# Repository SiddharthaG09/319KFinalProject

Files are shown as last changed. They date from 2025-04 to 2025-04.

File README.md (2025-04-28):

# 319KFinalProject

For our final project, we recreated Space Invaders in C, using a custom-designed PCB and an MSPM0G3507 microcontroller. The game integrates hardware components including buttons, a slide potentiometer, and a DAC to control gameplay elements. We designed, printed, and assembled the PCB ourselves, and developed the game logic and graphics from scratch to run on the microcontroller.

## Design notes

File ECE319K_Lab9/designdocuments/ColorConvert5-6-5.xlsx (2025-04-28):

red | green | blue | 565
0 | 255 | 120 | 0x7FE0 | 0x7FE0, // 0, 255, 120

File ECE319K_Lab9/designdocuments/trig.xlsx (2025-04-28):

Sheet: 64
 | 2 |  | 64
angle | vx | vy | ix | iy
0 | 2 | 0 | 128 | 0
0.09817477042 | 1.990369453 | 0.1960342807 | 127 | 13
0.1963495408 | 1.961570561 | 0.390180644 | 126 | 25
0.2945243113 | 1.913880671 | 0.5805693545 | 122 | 37
0.3926990817 | 1.847759065 | 0.7653668647 | 118 | 49
0.4908738521 | 1.763842529 | 0.9427934737 | 113 | 60
0.5890486225 | 1.662939225 | 1.111140466 | 106 | 71
0.687223393 | 1.546020907 | 1.268786568 | 99 | 81
0.7853981634 | 1.414213562 | 1.414213562 | 91 | 91
0.8835729338 | 1.268786568 | 1.546020907 | 81 | 99
0.9817477042 | 1.111140466 | 1.662939225 | 71 | 106
1.079922475 | 0.9427934737 | 1.763842529 | 60 | 113
1.178097245 | 0.7653668647 | 1.847759065 | 49 | 118
1.276272016 | 0.5805693545 | 1.913880671 | 37 | 122
1.374446786 | 0.390180644 | 1.961570561 | 25 | 126
1.472621556 | 0.1960342807 | 1.990369453 | 13 | 127
1.570796327 | -7.656635742e-16 | 2 | 0 | 128
1.668971097 | -0.1960342807 | 1.990369453 | -13 | 127
1.767145868 | -0.390180644 | 1.961570561 | -25 | 126
1.865320638 | -0.5805693545 | 1.913880671 | -37 | 122
1.963495408 | -0.7653668647 | 1.847759065 | -49 | 118
2.061670179 | -0.9427934737 | 1.763842529 | -60 | 113
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

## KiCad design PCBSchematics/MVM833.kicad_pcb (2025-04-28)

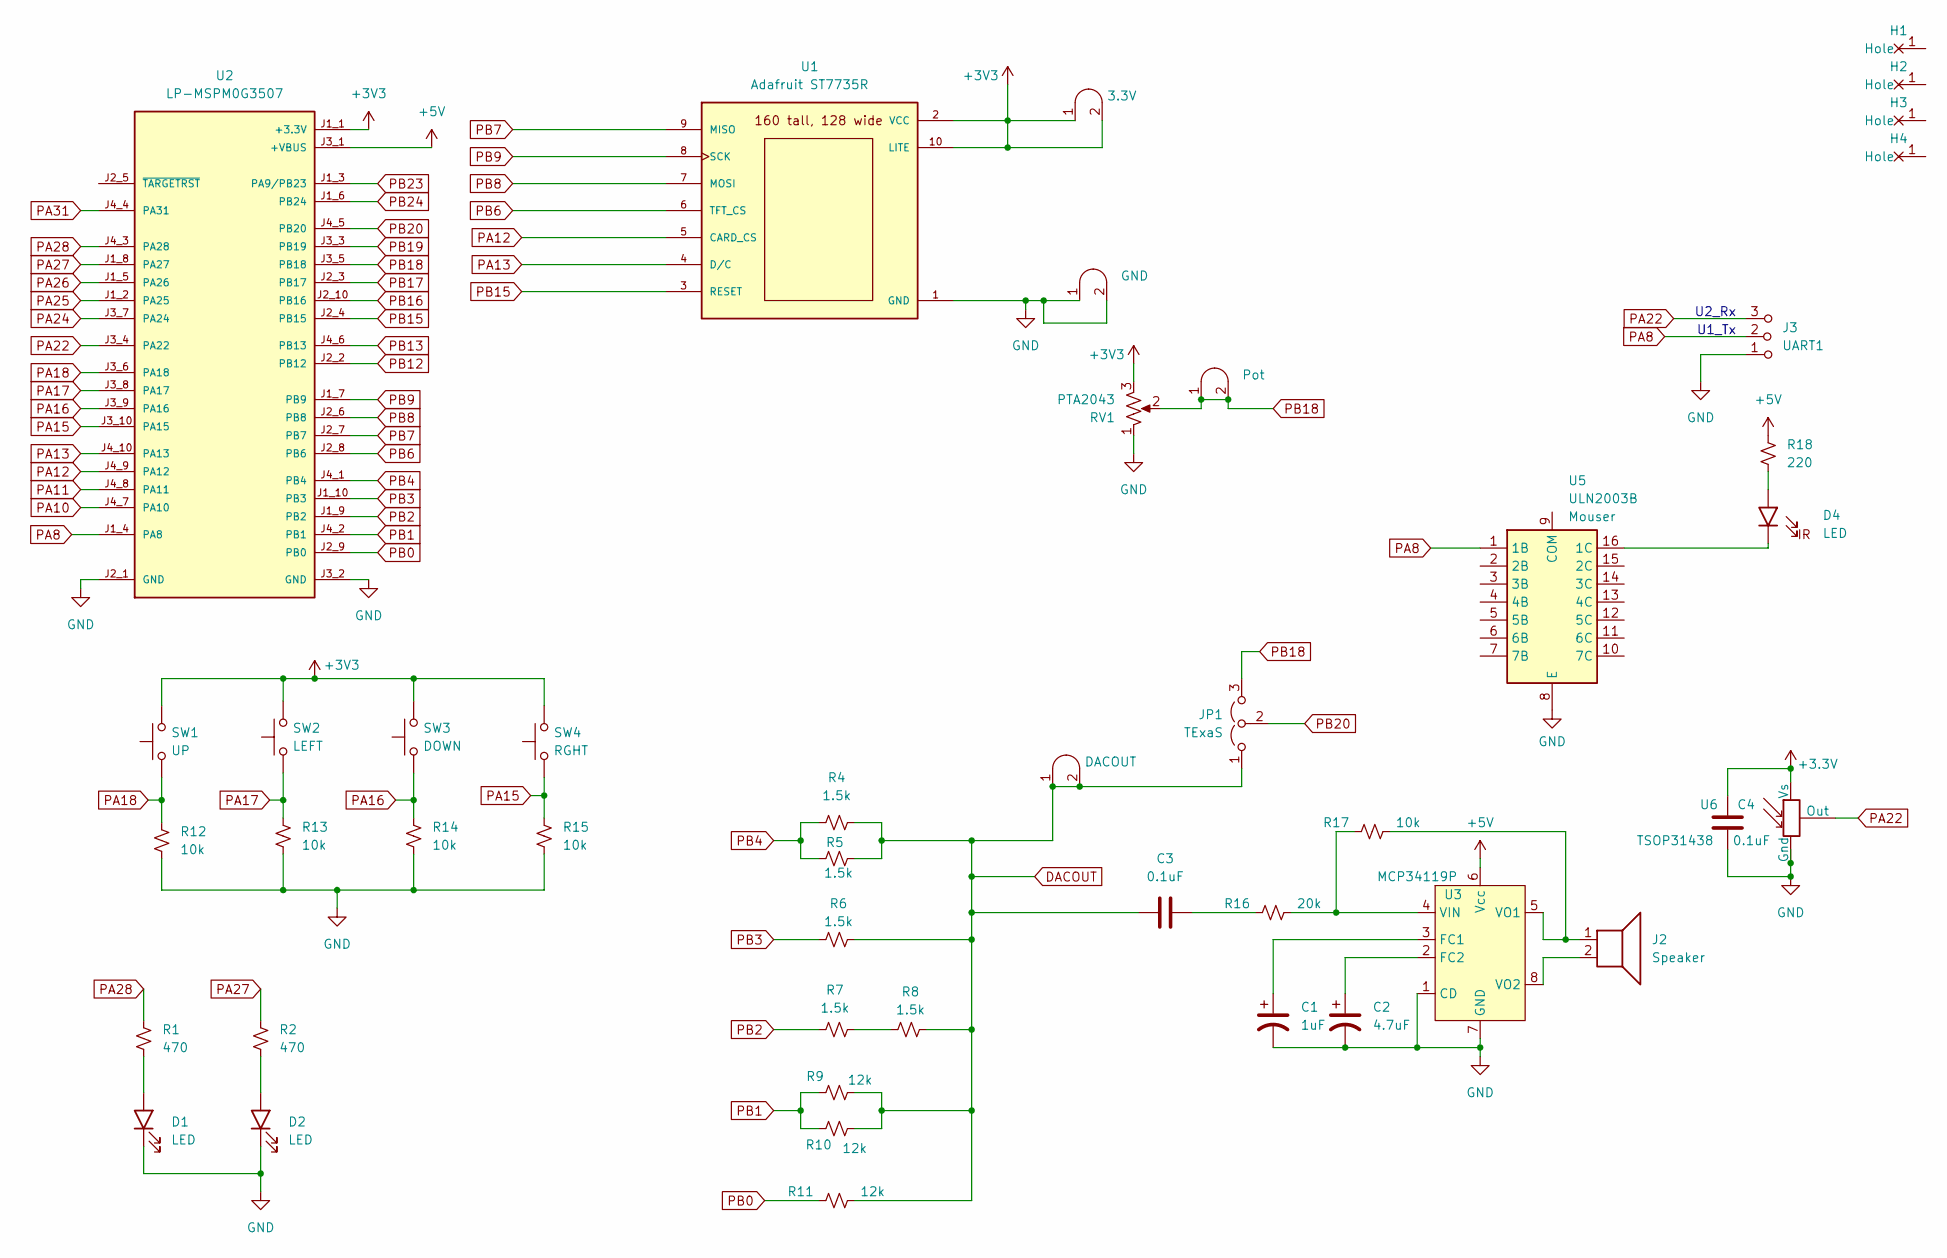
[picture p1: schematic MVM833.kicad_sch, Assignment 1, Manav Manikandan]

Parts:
C1: 1uF; CP_Radial_Tantal200mil
C2: 4.7uF; CP_Radial_Tantal200mil
C3, C4: 0.1uF; C_Axial_200mil
D1, D2, D4: LED; LED_D5.0mm
H1, H2, H3, H4: MountingHole_4_40
J2: Speaker; PinHeader_1x02_P2.54mm_Vertical
J3: UART1; PinHeader_1x03_P2.54mm_Vertical
J4: Pot; Testpoint_1x02_P2.54mm
J6: GND; Testpoint_1x02_P2.54mm
J7: DACOUT; Testpoint_1x02_P2.54mm
JP1: TExaS; PinHeader_1x03_P2.54mm_Vertical
R1, R2: 470; R_Axial_DIN0204_L3.6mm_D1.6mm_P7.62mm_Horizontal
R4, R5, R6, R7, R8: 1.5k; R_Axial_DIN0204_L3.6mm_D1.6mm_P7.62mm_Horizontal
R9, R10, R11: 12k; R_Axial_DIN0204_L3.6mm_D1.6mm_P7.62mm_Horizontal
R12, R13, R14, R15, R17: 10k; R_Axial_DIN0204_L3.6mm_D1.6mm_P7.62mm_Horizontal
R16: 20k; R_Axial_DIN0204_L3.6mm_D1.6mm_P7.62mm_Horizontal
R18: 220; R_Axial_DIN0204_L3.6mm_D1.6mm_P7.62mm_Horizontal
RV1: PTA2043; PTA2043pot
SW1: UP; SW_PUSH_6mm
SW2: LEFT; SW_PUSH_6mm
SW3: DOWN; SW_PUSH_6mm
SW4: RGHT; SW_PUSH_6mm
TP1: 3.3V; Testpoint_1x02_P2.54mm
U1: Adafruit ST7735R; adafruit_st7735r
U2: LP-MSPM0G3507; ti_LP_MSPM0G3507
U3: MCP34119P; DIP-8_W7.62mm_LongPads
U5: ULN2003B; DIP-16_W7.62mm
U6: TSOP31438

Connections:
+3.3V: C4.1, U6.2 (Vs)
+3V3: RV1.3, SW1.2, SW2.2, SW3.2, SW4.2, TP1.1 (A), TP1.2 (B), U1.2 (VCC), U1.10 (LITE), U2.J1_1 (+3.3V)
+5V: R18.1, U2.J3_1 (+VBUS), U3.6 (Vcc)
DACOUT: C3.1, J7.1 (A), J7.2 (B), JP1.1 (A), R4.1, R5.1, R6.1, R8.1, R9.1, R10.1, R11.1
GND: C1.2, C2.2, C4.2, D1.1 (K), D2.1 (K), J3.1 (A), J6.1 (A), J6.2 (B), R12.2, R13.2, R14.2, R15.2, RV1.1, U1.1 (GND), U2.J2_1 (GND), U2.J3_2 (GND), U3.1 (CD), U3.7 (GND), U5.8 (E), U6.1 (Gnd)
unnamed: C3.2, R16.2
unnamed: D1.2 (A), R1.2
unnamed: D2.2 (A), R2.2
unnamed: D4.2 (A), R18.2
unnamed: D4.1 (K), U5.16 (1C)
unnamed: R7.1, R8.2
unnamed: C1.1, U3.3 (FC1)
unnamed: C2.1, U3.2 (FC2)
unnamed: R16.1, R17.2, U3.4 (VIN)
unnamed: J2.1, R17.1, U3.5 (VO1)
unnamed: J2.2, U3.8 (VO2)
PA8: J3.2 (B), U2.J1_4 (PA8), U5.1 (1B)
PA10: U2.J4_7 (PA10)
PA11: U2.J4_8 (PA11)
PA12: U1.5 (CARD_CS), U2.J4_9 (PA12)
PA13: U1.4 (D/C), U2.J4_10 (PA13)
PA15: R15.1, SW4.1, U2.J3_10 (PA15)
PA16: R14.1, SW3.1, U2.J3_9 (PA16)
PA17: R13.1, SW2.1, U2.J3_8 (PA17)
PA18: R12.1, SW1.1, U2.J3_6 (PA18)
PA22: J3.3 (C), U2.J3_4 (PA22), U6.3 (Out)
PA24: U2.J3_7 (PA24)
PA25: U2.J1_2 (PA25)
PA26: U2.J1_5 (PA26)
PA27: R2.1, U2.J1_8 (PA27)
PA28: R1.1, U2.J4_3 (PA28)
PA31: U2.J4_4 (PA31)
PB0: R11.2, U2.J2_9 (PB0)
PB1: R9.2, R10.2, U2.J4_2 (PB1)
PB2: R7.2, U2.J1_9 (PB2)
PB3: R6.2, U2.J1_10 (PB3)
PB4: R4.2, R5.2, U2.J4_1 (PB4)
PB6: U1.6 (TFT_CS), U2.J2_8 (PB6)
PB7: U1.9 (MISO), U2.J2_7 (PB7)
PB8: U1.7 (MOSI), U2.J2_6 (PB8)
PB9: U1.8 (SCK), U2.J1_7 (PB9)
PB12: U2.J2_2 (PB12)
PB13: U2.J4_6 (PB13)
PB15: U1.3 (RESET), U2.J2_4 (PB15)
PB16: U2.J2_10 (PB16)
PB17: U2.J2_3 (PB17)
PB18: J4.1 (A), J4.2 (B), JP1.3 (B), RV1.2, U2.J3_5 (PB18)
PB19: U2.J3_3 (PB19)
PB20: JP1.2 (C), U2.J4_5 (PB20)
PB23: U2.J1_3 (PA9/PB23)
PB24: U2.J1_6 (PB24)

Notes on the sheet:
U2_Rx
U1_Tx

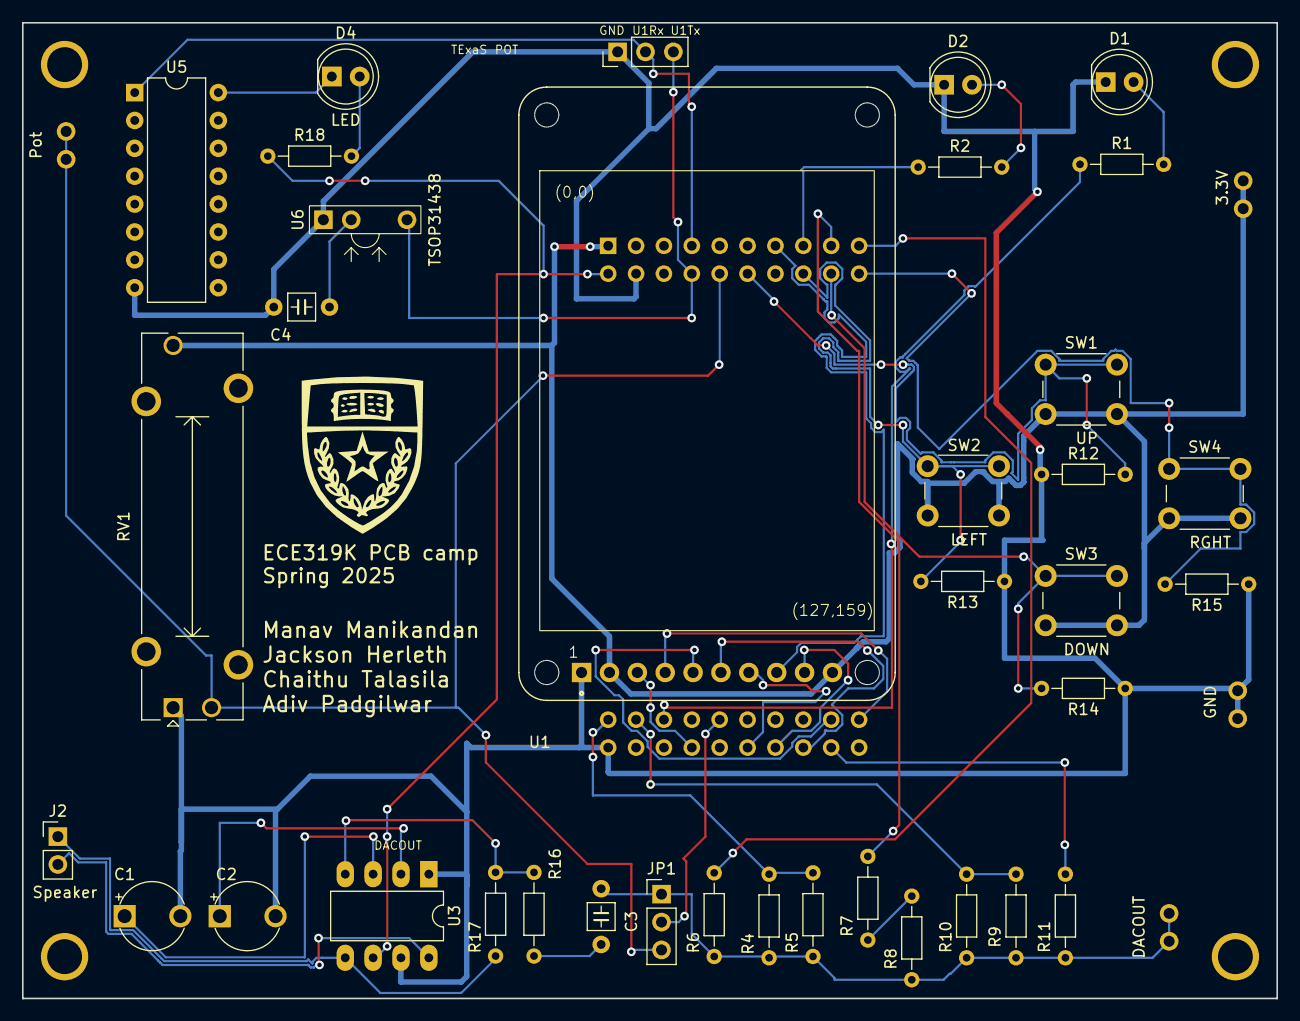
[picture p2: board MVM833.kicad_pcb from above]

Board: 2 copper layers, 114.3 x 88.9 mm, 45 parts (1 on the bottom side), 38 nets.

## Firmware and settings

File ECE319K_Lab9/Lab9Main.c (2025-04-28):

// Lab9Main.c
// Runs on MSPM0G3507
// Lab 9 ECE319K
// Your name
// Last Modified: 12/26/2024

#include <stdio.h>
#include <stdint.h>
#include <ti/devices/msp/msp.h>
#include "../inc/ST7735.h"
#include "../inc/Clock.h"
#include "../inc/LaunchPad.h"
#include "../inc/TExaS.h"
#include "../inc/Timer.h"
#include "../inc/ADC1.h"
#include "../inc/DAC5.h"
#include "../inc/Arabic.h"
#include "SmallFont.h"
#include "LED.h"
#include "Switch.h"
#include "Sound.h"
#include "images/images.h"
#include <stdlib.h>
#include <time.h>

int getRandomval(void) {
  return (rand() % (40 - 5 + 1)) + 5;
}

// PLL / clock setup
void PLL_Init(void){
  Clock_Init80MHz(0);
}

// Arabic demo data (unchanged)
Arabic_t ArabicAlphabet[] = {
  alif, ayh, baa, daad, daal, dhaa, dhaal,
  faa, ghayh, haa, ha, jeem, kaaf, khaa,
  laam, meem, noon, qaaf, raa, saad, seen,
  sheen, ta, thaa, twe, waaw, yaa, zaa,
  space, dot, null
};
Arabic_t Hello[] = { alif, baa, ha, raa, meem, null };
Arabic_t WeAreHonoredByYourPresence[] = { alif, noon, waaw, ta, faa, raa, sheen, null };

// simple 32-bit LCG for wider random range
static uint32_t M = 1;
uint32_t Random32(void){
  M = 1664525*M + 1013904223;
  return M;
}
uint32_t Random(uint32_t n){
  return (Random32() >> 16) % n;
}

// TExaS helper for PB27/PB26
uint8_t TExaS_LaunchPadLogicPB27PB26(void){
  return (0x80 | ((GPIOB->DOUT31_0 >> 26) & 0x03));
}

// language/phrase tables (unchanged)
typedef enum { English, Spanish, Portuguese, French } Language_t;
typedef enum { HELLO, GOODBYE, LANGUAGE } phrase_t;
const char Hello_English[]    = "Hello";
const char Hello_Spanish[]    = "\xADHola!";
const char Hello_Portuguese[] = "Ol\xA0";
const char Hello_French[]     = "All\x83";
const char Goodbye_English[]    = "Goodbye";
const char Goodbye_Spanish[]    = "Adi\xA2s";
const char Goodbye_Portuguese[] = "Tchau";
const char Goodbye_French[]     = "Au revoir";
const char Language_English[]    = "English";
const char Language_Spanish[]    = "Espa\xA4ol";
const char Language_Portuguese[] = "Portugu\x88s";
const char Language_French[]     = "Fran\x87" "ais";
const char *Phrases[3][4] = {
  { Hello_English, Hello_Spanish, Hello_Portuguese, Hello_French },
  { Goodbye_English, Goodbye_Spanish, Goodbye_Portuguese, Goodbye_French },
  { Language_English, Language_Spanish, Language_Portuguese, Language_French }
};

// game state
uint32_t laseractive = 0;
uint32_t score       = 0;
volatile uint32_t slideplot = 0;
uint32_t flag        = 1;
uint32_t end         = 0;
uint32_t respawn     = 0;

typedef struct {
  uint16_t *pic;
  int32_t posx, posy;
  int32_t w, l;
  int32_t health;
  int32_t vx, vy;
  int32_t prevx, prevy;
} ship_t;

ship_t bguys, me, laser;

// initialize enemy: full-width spawn, random speeds & drift
void bguys_init(void) {
  bguys.pic    = SmallEnemy30pointA;
  bguys.health = 1;
  bguys.w      = 16;
  bguys.l      = 10;

  // spawn X anywhere in [0, 128 - w]
  bguys.posx = Random(128 - bguys.w);
  bguys.posy = 5;

  // vertical speed ∈ {1,2,3}
  bguys.vy = Random(3) + 1;

  // horizontal speed ∈ { -2,-1,0,+1,+2 }
  {
    int dir = (int)Random(3) - 1;   // -1,0,+1
    int mag = (int)Random(2) + 1;   //  1,2
    bguys.vx = dir * mag;
  }

  bguys.prevx = bguys.posx;
  bguys.prevy = bguys.posy;
}

void me_init(void) {
  me.pic    = PlayerShip0;
  me.health = 2;
  me.w      = 18;
  me.l      =  8;
  me.posx   =  0;
  me.posy   = 155;
  me.vx     =  0;
  me.vy     =  0;
  me.prevx  = me.posx;
  me.prevy  = me.posy;
}

void laser_init(void) {
  laser.pic    = ycoin;
  laser.w      = 16;
  laser.l      = 16;
  laser.health =  1;
  laser.posx   =  0;
  laser.posy   =  0;
  laser.vx     =  0;
  laser.vy     =  0;
  laser.prevx  =  0;
  laser.prevy  =  0;
}

// only fire when PA17 (bit 1) is pressed
void shoot_laser(void) {
  Clock_Delay1ms(15);
  uint32_t sw = Switch_In();
  if ((sw & 0x02) == 0) {
    return;
  }
  if (laseractive == 0) {
    laseractive = 1;
    laser.posx  = me.posx + (me.w/2 - laser.w/2);
    laser.posy  = me.posy;
    laser.vy    = -4;
    Sound_Shoot();
  }
}

void laserhit(void) {
  if (!laseractive) return;
  laser.posy += laser.vy;
  if (laser.posy <= 30) {
    laseractive = 0;
    return;
  }
  // collision test
  if (bguys.health > 0 &&
      laser.posx <  bguys.posx + bguys.w &&
      laser.posx + laser.w > bguys.posx &&
      laser.posy <  bguys.posy + bguys.l &&
      laser.posy + laser.l > bguys.posy) {
    bguys.health = 0;
    Sound_Explosion();
    Clock_Delay1ms(1);
    Sound_Explosion();
    laseractive = 0;
    score++;
    respawn = 1;
  }
}

// game tick: move enemy, player, laser, handle bounce & death
void cont(void) {
  bguys.prevx = bguys.posx;
  bguys.prevy = bguys.posy;

  if (respawn) {
    bguys_init();
    respawn = 0;
  }

  // update player from slide pot
  slideplot = ADCin();
  Clock_Delay1ms(10);
  me.prevx = me.posx;
  me.posx  = slideplot >> 5;

  // horizontal drift + edge bounce
  bguys.posx += bguys.vx;
  if (bguys.posx <= 0 || bguys.posx >= (128 - bguys.w)) {
    bguys.vx = -bguys.vx;
    if (bguys.posx < 0) bguys.posx = 0;
    else if (bguys.posx > (128 - bguys.w)) bguys.posx = 128 - bguys.w;
  }

  // vertical motion & end‐game
  if (bguys.health) {
    if (bguys.posy > 150) {
      bguys.health = 0;
      Sound_Killed();
      end = 1;
    } else {
      bguys.posy += bguys.vy;
    }
  }

  // laser movement & collision
  if (laseractive) {
    laser.prevx = laser.posx;
    laser.prevy = laser.posy;
    laser.posy += laser.vy;
  }
  if (laser.posy < -1) {
    laseractive = 0;
  }
  laserhit();
}

void draw(void) {
  // erase old
  ST7735_DrawBitmap(me.prevx,    me.prevy,    PlayerShipBlank, me.w,    me.l);
  ST7735_DrawBitmap(bguys.prevx, bguys.prevy, SmallEnemyBlank, bguys.w, bguys.l);
  ST7735_DrawBitmap(laser.prevx, laser.prevy, LaserBlank,      laser.w, laser.l);
  // draw new
  ST7735_DrawBitmap(me.posx,    me.posy,    me.pic,    me.w,    me.l);
  if (bguys.health) {
    ST7735_DrawBitmap(bguys.posx, bguys.posy, bguys.pic, bguys.w, bguys.l);
  }
  if (laseractive) {
    ST7735_DrawBitmap(laser.posx, laser.posy, laser.pic, laser.w, laser.l);
  }
}

// main game entry
int main(void) {
  __disable_irq();
  PLL_Init();
  LaunchPad_Init();
  SysTick_IntArm(400000,2);
  ST7735_InitR(INITR_GREENTAB);
  ST7735_FillScreen(ST7735_BLACK);

  ADCinit();
  Switch_Init();
  LED_Init();
  Sound_Init();

  me_init();
  bguys_init();
  laser_init();

  TExaS_Init(0, 0, &TExaS_LaunchPadLogicPB27PB26);

  // choose language (just burns cycles here)
  ST7735_OutString("*Espanol ");
  ST7735_OutString("or ");
  ST7735_OutString("*English ");
  uint32_t but = 0;
  while ((but = Switch_In()) == 0) { /* wait */ }

  // start the 30Hz tick
  ST7735_FillScreen(ST7735_BLACK);
  TimerG12_IntArm(80000000/30, 3);
  __enable_irq();
  ST7735_FillScreen(ST7735_BLACK);

  // game loop
  while (1) {
    if (flag) {
      draw();
      flag = 0;
    }
    if (end) {
      // show final
      ST7735_FillScreen(ST7735_BLACK);
      if (but == 2) {
        ST7735_SetCursor(1,3);
        ST7735_OutString("juego TERMINANDO!");
        ST7735_SetCursor(1,6);
        ST7735_OutString("Puntaje ");
        ST7735_OutUDec(score);
        ST7735_SetCursor(1,8);
        ST7735_OutString("Presione cualquier botón");
        ST7735_SetCursor(1,10);
        ST7735_OutString("para reiniciar");
        Sound_Explosion();
      } else {
        ST7735_SetCursor(1,3);
        ST7735_OutString("Game OVER!");
        ST7735_SetCursor(1,6);
        ST7735_OutString("Score ");
        ST7735_OutUDec(score);
        ST7735_SetCursor(1,8);
        ST7735_OutString("Press any button");
        ST7735_SetCursor(1,10);
        ST7735_OutString("to restart");
        Sound_Explosion();
      }
      // two-line restart prompt

      for (int i = 0; i < 5; i++) {
        Sound_Highpitch();
      }

      // wait for press
      while (Switch_In() == 0) { }
      Clock_Delay1ms(200);

      // reset game
      score   = 0;
      end     = 0;
      respawn = 1;
      me_init();
      bguys_init();
      laser_init();
      ST7735_FillScreen(ST7735_BLACK);
    }
  }
}

// TimerG12 ISR drives our 30Hz tick
void TIMG12_IRQHandler(void) {
  if (TIMG12->CPU_INT.IIDX == 1) {
    if (!laseractive) {
      shoot_laser();
    }
    cont();
    flag = 1;
  }
}

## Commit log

2025-04-28 Added Project Folder
    [ColorConvert5-6-5.xlsx, trig.xlsx]
2025-04-28 Uploaded PCB
    [MVM833.kicad_pcb, MVM833.kicad_sch]
